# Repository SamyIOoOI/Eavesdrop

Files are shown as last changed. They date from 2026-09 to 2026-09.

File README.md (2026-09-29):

<h1 align="center">Eavesdrop</h1>

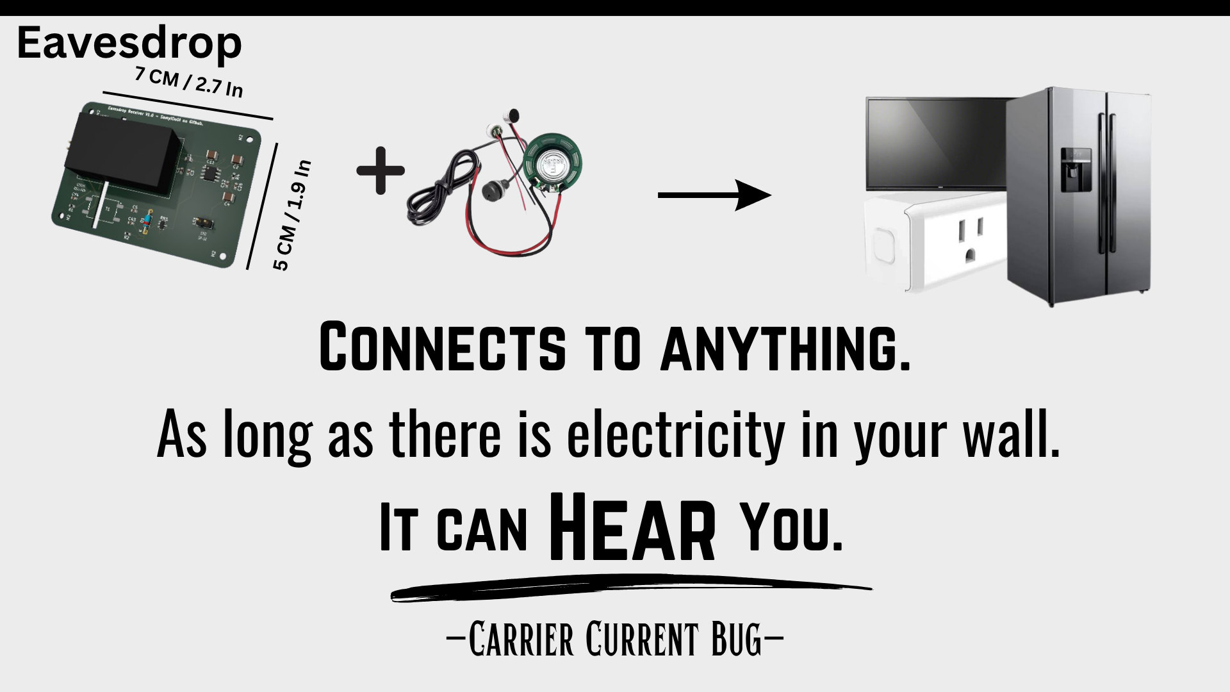
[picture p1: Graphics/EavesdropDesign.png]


### <p align="center">[Main Features](#main-features) **-** [Usage](#usage-of-eavesdrop) **-** [PCB & Schematic](#design) **-** [Gerber Files](/Eavesdrop/Gerber%20Files/) **-** [Kicad (Schematic & PCB)](/Eavesdrop/Kicad%20Source%20Files/)  **-** [BOM](#bom)  **-** [BOM (File)](/BOM/evasdrop.xlsx) **-** [Credits](#credits)</p>

## How would you feel if your own fridge was spying on you? Maybe even your tv, maybe the fryer, maybe the wall outlet you charge this device with. maybe even your charger. Well that could very well be a carrier bug. Just like Eavesdrop.

*A "current carrier bug" is a spy tool that records the sound inside the area its plugged in and sends it back through the AC power its connected to directly, evading most detection devices available in the market that rely on RF to detect these devices.*

----------------

**<p align="center">No matter where you are. The bug listens as long as there's electricity flowing in the bugged device.<p>**

---------------

## Main Features

- Undetectable (via RF Detectors that are commonly used)
- Secretive (but requires prior access to the room)

- **Can be planted into any device, your lamp, your tv, your pc, ANYTHING can become a bug with one plug.**

## Usage of Eavesdrop

1- Insert it into the outlet or any device that takes in power from the wall and make sure the microphone jack is connected to proper microphone element such as an electret mic.

2- Connect the passive & active AC wires to their respective locations via the male header on the pcb, each header reads if its N (neutral) or L (live). 
Reversal could cause irreversible damage. Use a test screw driver to make sure you're connecting the right ones.

3- connect the receiver , when required to listen to the broadcast, to an outlet that is in the same grid as the target room/building.

4- Make sure that both the receiver and the sender are at the same wavelength via calibration. Refer to the schemati for more details.

5- Use the volume control knob to increase/decrease th sound level.

<br>

<p align="center">Note that usage of Eavesdrop or any other spying device is illegal when taken out of personal hobby boundaries and used beyond one's own property. (If your device bleeds into the grid of neighbouring properties you may still be fined.) <br><br> I hold no responsiblity on the misuse of this project for illegal activities such as but not limited to: Unathorized Surveillance, Stalking, and damage to property.<br><br>My work is done for the sake of open-sourcing, eduction and self-learning. Not to inflict harm.<p>

## Design

Eavesdrop Sender Schematic

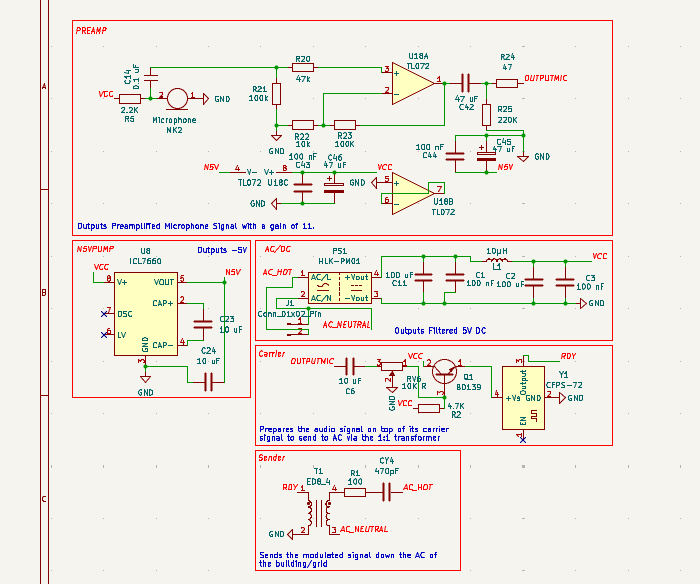
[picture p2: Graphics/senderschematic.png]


Eavesdrop Sender PCB

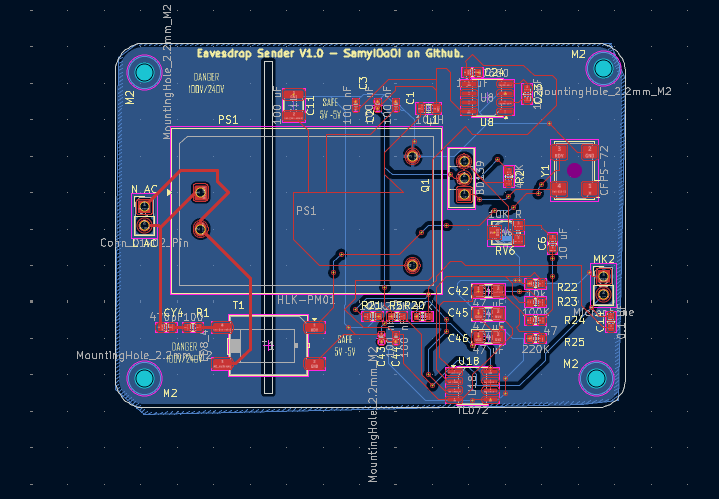
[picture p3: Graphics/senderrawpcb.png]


Eavesdrop Sender PCB (Model)

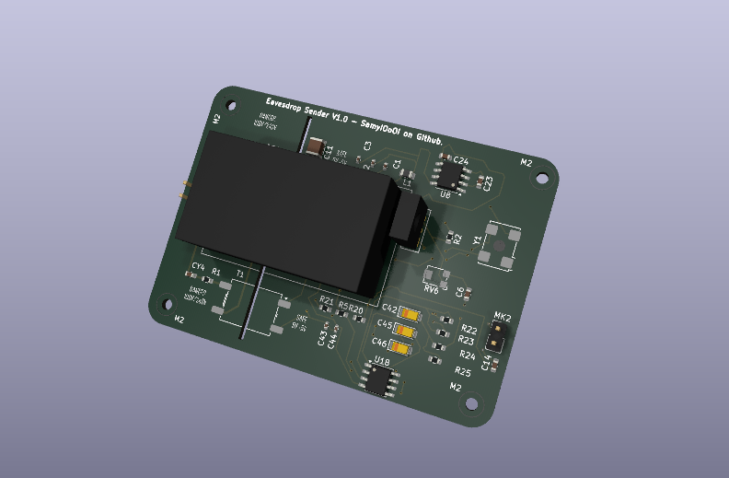
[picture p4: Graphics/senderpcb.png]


Eavesdrop Receiver Schematic

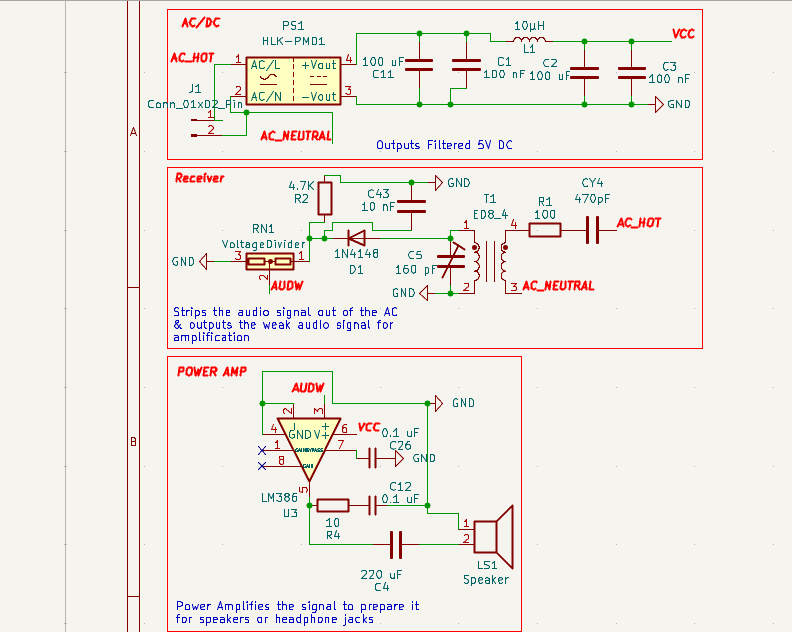
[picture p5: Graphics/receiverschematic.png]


Eavesdrop Receiver PCB

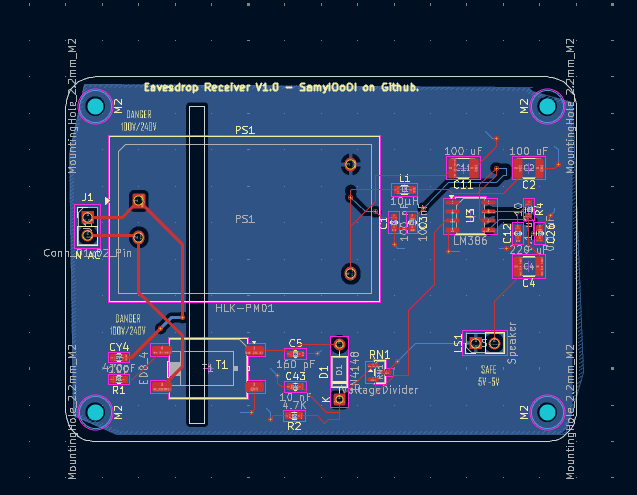
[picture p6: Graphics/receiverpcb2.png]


Eavesdrop Receiver PCB (Model)

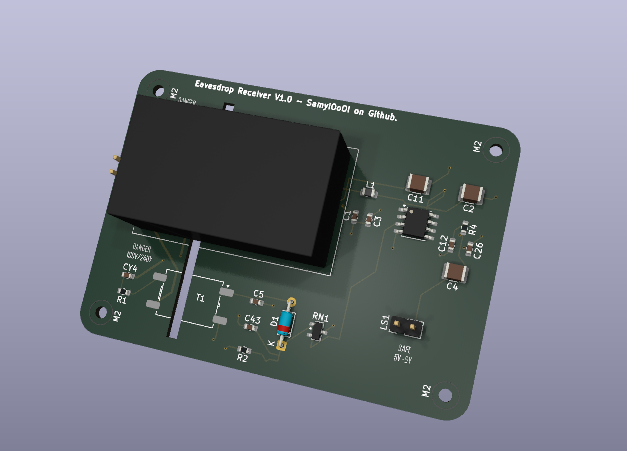
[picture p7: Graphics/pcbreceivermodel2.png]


## BOM

| **Part Name** | **Quantity** | **Price** | **Link** |
|---|---|---|---|
| **2.54mm 1x2 Pin Header** | 2 | 89.04 | https://www.digikey.com/en/products/detail/samtec-inc/TSW-102-26-S-S/1103922 |
| **Capacitor 0.1 uF** | 3 | 41.93 | https://www.digikey.com/en/products/detail/vishay-beyschlag-draloric-bc-components/K104K10X7RF5UH5/2356754 |
| **Capacitor 10 nF** | 1 | 5.18 | https://www.digikey.com/en/products/detail/samsung-electro-mechanics/CL21B103KBANNNC/3886673 |
| **Capacitor 10 uF** | 3 | 29.51 | https://www.digikey.com/en/products/detail/kemet/ESK106M050AC3DA/13176616 |
| **Capacitor 100 nF** | 6 | 83.87 | https://www.digikey.com/en/products/detail/vishay-beyschlag-draloric-bc-components/K104K10X7RF5UH5/2356754 |
| **Capacitor 100 uF** | 4 | 115.96 | https://www.digikey.com/en/products/detail/rubycon/35TZV100M6-3X8/3134900 |
| **Capacitor 160 pF** | 1 | 1.09 | https://www.digi-electronics.com/en/products/detail/murata-electronics/GCM1885C2A161JA16D/7169978.html |
| **Capacitor 220 uF** | 1 | 31.76 | https://www.lcsc.com/product-detail/C133440.html |
| **Capacitor 47 uF** | 3 | 65.23 | https://www.digikey.com/en/products/detail/rubycon/63ZLJ47M6-3X11/3134467 |
| **Capacitor 470pF** | 2 | 1.00 | https://uge-one.com/product/ceramic-capacitor-470pf/ |
| **Condenser Microphone** | 1 | 6.00 | https://makerselectronics.com/product/condenser-microphone-2-pins/ |
| **Crystal/Oscillator CFPS-72** | 1 | 168.77 | https://www.digikey.com/en/products/detail/ecs-inc/ECS-100AX-035/827253 |
| **Diode 1N4148** | 1 | 5.18 | https://www.digikey.com/en/products/detail/onsemi/1N4148/458603 |
| **IC ICL7660** | 1 | 51.30 | https://uge-one.com/product/icl7660/ |
| **IC LM386** | 1 | 55.91 | https://www.digikey.com/en/products/detail/texas-instruments/LM386N-1-NOPB/6284 |
| **IC TL072** | 1 | 24.48 | https://www.lcsc.com/product-detail/C7236.html |
| **Inductor 10µH** | 2 | 11.39 | https://www.digikey.com/en/products/detail/tdk/MLZ2012M100WTD25/4743190 |
| **Potentiometer 10K** | 1 | 96.29 | https://www.digikey.com/en/products/detail/tt-electronics-bi/P160KN-0QD15B10K/2408885 |
| **Power Supply HLK-PM01 (AC-DC 5V 3W)** | 2 | 320.00 | https://makerselectronics.com/product/hlk-pm01-ac-dc-power-module/ |
| **Resistor 10** | 1 | 0.15 | https://makerselectronics.com/product/carbon-resistor-10%cf%89-0-25w-through-hole/ |
| **Resistor 100** | 2 | 2.50 | https://uge-one.com/product/resistor-1w-carbon-film-5-tolerance-100r-ohm/ |
| **Resistor 100K** | 2 | 0.30 | https://makerselectronics.com/product/carbon-resistor-100k-0-25w/ |
| **Resistor 10K** | 1 | 0.10 | https://makerselectronics.com/product/carbon-resistor-10k%cf%89-0-125w-through/ |
| **Resistor 2.2K** | 1 | 0.10 | https://makerselectronics.com/product/carbon-resistor-2-2k%cf%89-0-125w-through-hole/ |
| **Resistor 220K** | 1 | 0.15 | https://makerselectronics.com/product/carbon-resistor-220k%cf%89-0-25w-through-hole/ |
| **Resistor 4.7K** | 2 | 0.50 | https://uge-one.com/product/carbon-resistor-0-25w-4-7k-ohm/ |
| **Resistor 47** | 1 | 1.00 | https://makerselectronics.com/product/carbon-resistor-47%cf%89-2w-through-hole/ |
| **Resistor 47K** | 1 | 0.15 | https://makerselectronics.com/product/carbon-resistor-47k%cf%89-0-25w/ |
| **Resistor VOLTAGEDIVIDER** | 1 | 0.15 | https://makerselectronics.com/product/carbon-resistor-100k-0-25w/ |
| **Speaker** | 1 | 60.00 | https://makerselectronics.com/product/speaker-8-ohm-10w-125x60mm/ |
| **Transformer ED8_4** | 2 | 755.84 | https://www.digikey.com/en/products/detail/pulse-electronics/HX0068ANL/3025742 |
| **Transistor BD139** | 1 | 4.50 | https://makerselectronics.com/product/bd139-1-5a-80v-npn-bipolar-power-transistor-to-126/ |
| **Total** | | 2029.33 EGP  | |

*Credits: BOM converted from XLSX to md on tableconvert.com*

## Credits

Made by SamyIOoOI on github under the GPL 3.0 Licence.



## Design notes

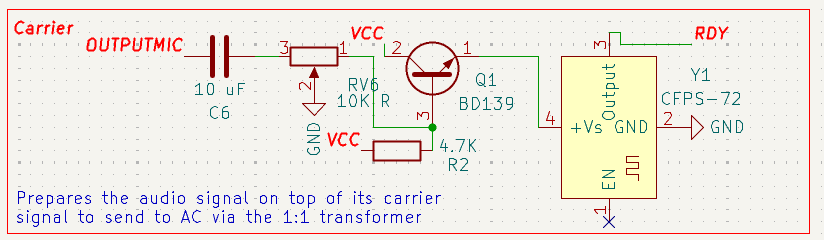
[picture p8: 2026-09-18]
Graphics/r.png

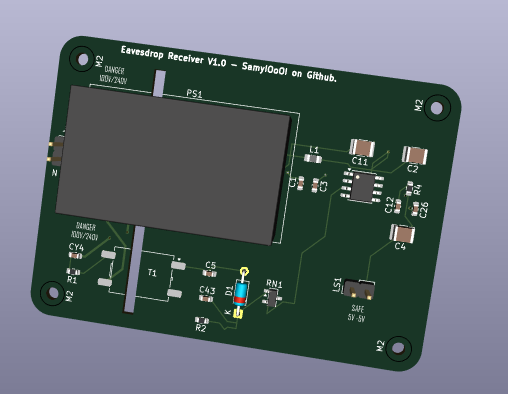
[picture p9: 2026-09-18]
Graphics/senderpcbpicture.png

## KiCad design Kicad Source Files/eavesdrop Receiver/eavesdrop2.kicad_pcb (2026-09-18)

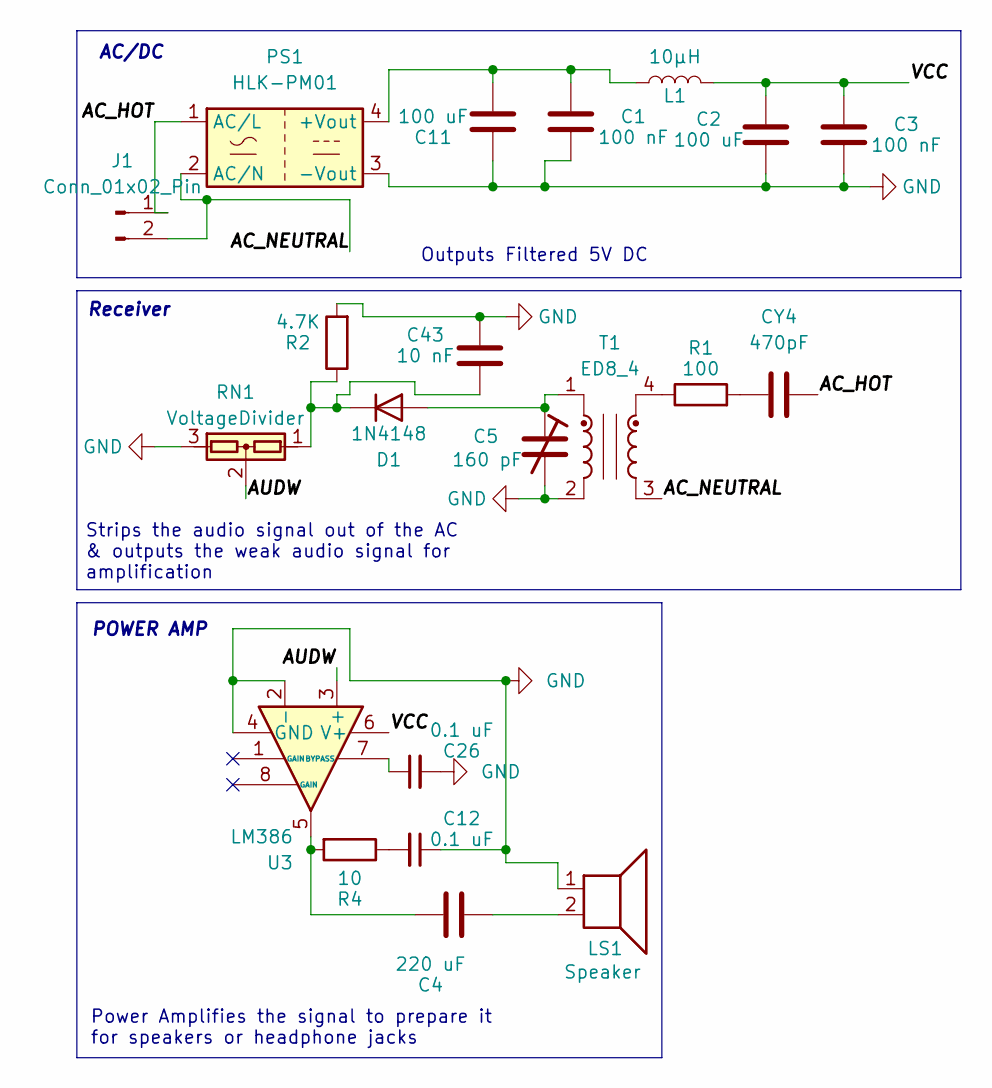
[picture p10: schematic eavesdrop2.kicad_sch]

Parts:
C1, C3: 100 nF; C_0603_1608Metric
C2, C11: 100 uF; C_1210_3225Metric
C4: 220 uF; C_1210_3225Metric
C5: 160 pF; C_0603_1608Metric
C12, C26: 0.1 uF; C_0603_1608Metric
C43: 10 nF; C_0603_1608Metric
CY4: 470pF; C_0603_1608Metric
D1: 1N4148; D_DO-35_SOD27_P7.62mm_Horizontal
J1: Conn_01x02_Pin; PinHeader_1x02_P2.54mm_Vertical
L1: 10µH; L_0805_2012Metric
LS1: Speaker; PinHeader_1x02_P2.54mm_Vertical
PS1: HLK-PM01; Converter_ACDC_Hi-Link_HLK-PMxx
R1: 100; R_0603_1608Metric
R2: 4.7K; R_0603_1608Metric
R4: 10; R_0603_1608Metric
RN1: VoltageDivider; SOT-23
T1: ED8_4; Transformer_ED8_4-Lead_10.5x8mm_P5mm
U3: LM386; SOIC-8_3.9x4.9mm_P1.27mm

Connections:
/AC_HOT: CY4.2, J1.1, PS1.1 (AC/L)
/AC_NEUTRAL: J1.2, PS1.2 (AC/N), T1.3
/AUDW: RN1.2, U3.3 (+)
/VCC: C2.2, C3.2, L1.2, U3.6 (V+)
GND: C1.1, C2.1, C3.1, C5.2, C11.1, C12.1, C26.2, C43.1, LS1.1, PS1.3 (-Vout), R2.2, RN1.3, T1.2, U3.2 (-), U3.4 (GND)
unnamed: C4.1, R4.2, U3.5
unnamed: C4.2, LS1.2
unnamed: C12.2, R4.1
unnamed: CY4.1, R1.2
unnamed: C5.1, D1.2 (A), T1.1
unnamed: C43.2, D1.1 (K), R2.1, RN1.1
unnamed: C1.2, C11.2, L1.1, PS1.4 (+Vout)
unnamed: R1.1, T1.4
unnamed: C26.1, U3.7 (BYPASS)

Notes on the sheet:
Strips the audio signal out of the AC & outputs the weak audio signal for amplification
Power Amplifies the signal to prepare it for speakers or headphone jacks
AC/DC
Receiver
POWER AMP
Outputs Filtered 5V DC

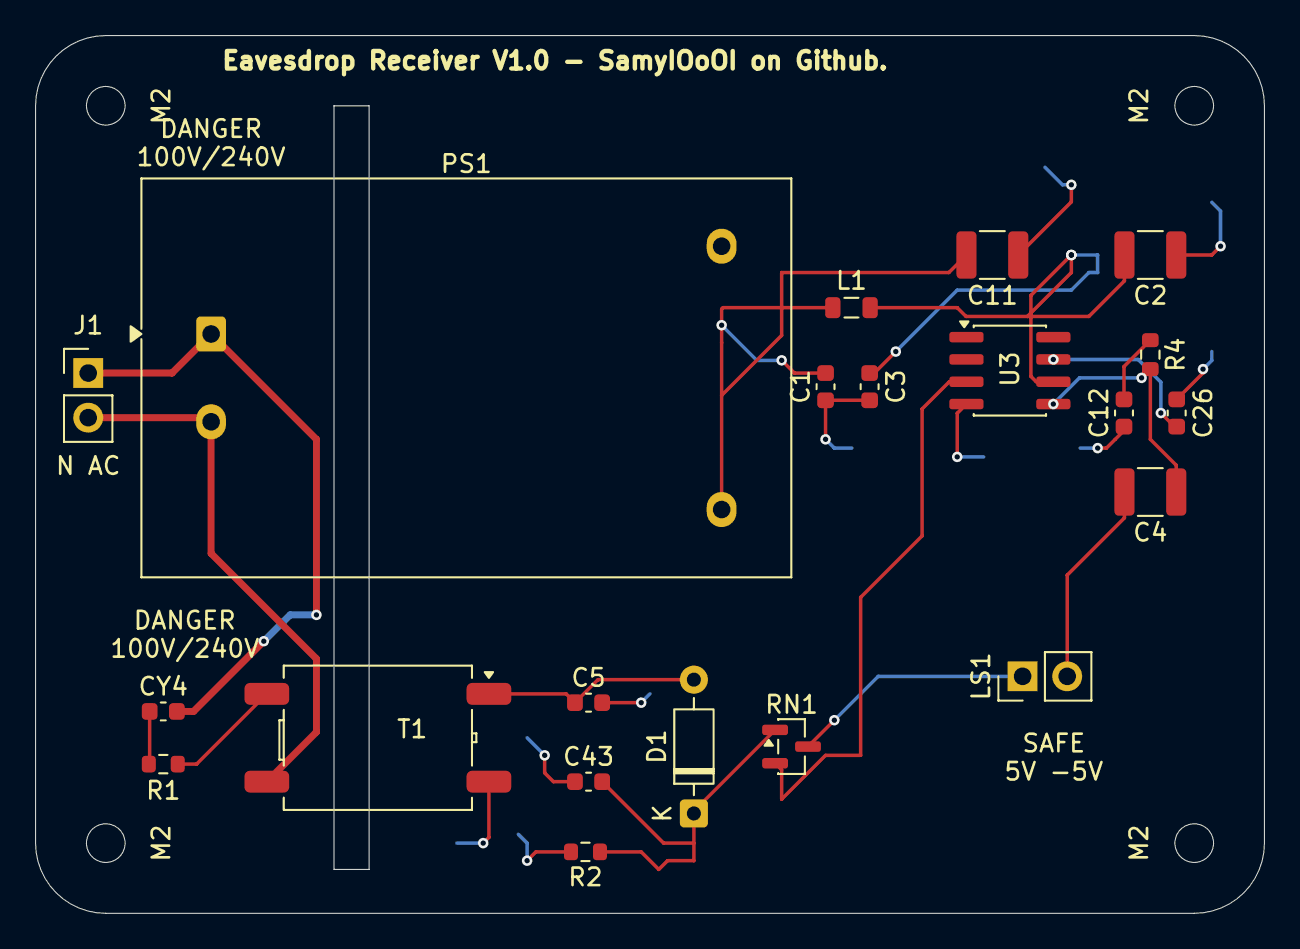
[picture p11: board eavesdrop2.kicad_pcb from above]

Board: 2 copper layers, 70.0 x 50.0 mm, 25 parts (0 on the bottom side), 14 nets.

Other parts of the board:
M2, M2#2, M2#3, M2#4: MountingHole_2.2mm_M2

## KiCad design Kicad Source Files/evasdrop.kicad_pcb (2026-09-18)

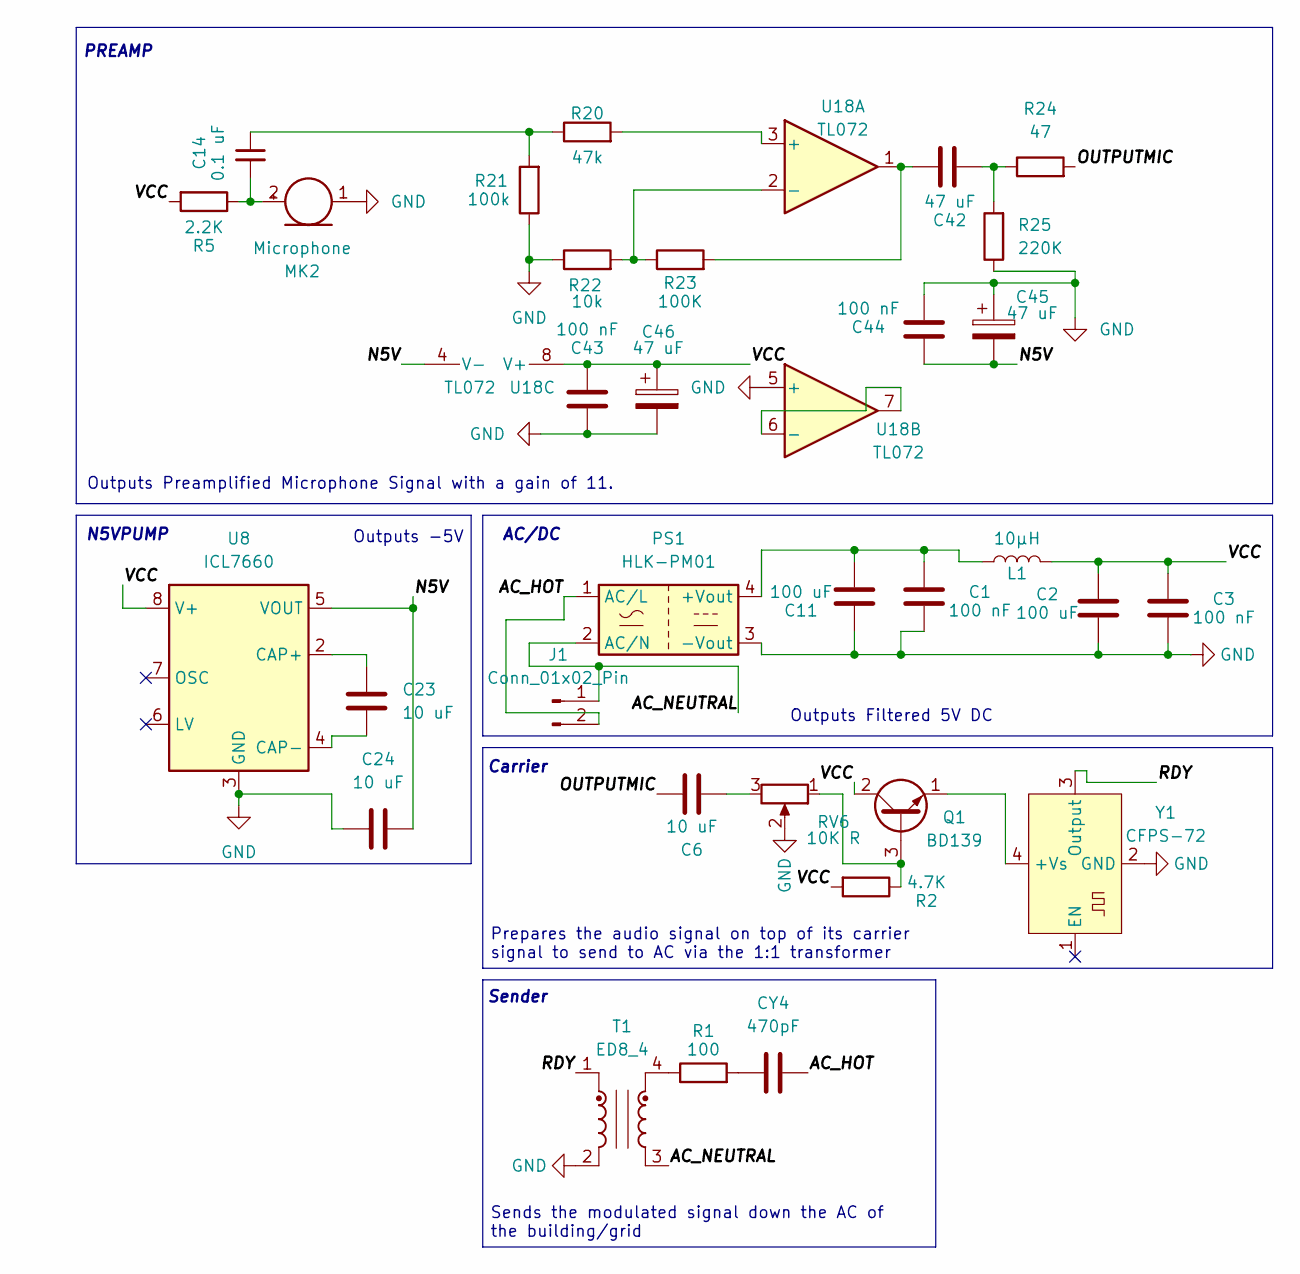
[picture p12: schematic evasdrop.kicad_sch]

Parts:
C1, C3, C43, C44: 100 nF; C_0402_1005Metric
C2: 100 uF; C_0402_1005Metric
C6, C23, C24: 10 uF; C_0603_1608Metric
C11: 100 uF; C_1210_3225Metric
C14: 0.1 uF; C_0603_1608Metric
C42, C45, C46: 47 uF; CP_EIA-3216-18_Kemet-A
CY4: 470pF; C_0603_1608Metric
J1: Conn_01x02_Pin; PinHeader_1x02_P2.54mm_Vertical
L1: 10µH; L_0805_2012Metric
MK2: Microphone; PinHeader_1x02_P2.54mm_Vertical
PS1: HLK-PM01; Converter_ACDC_Hi-Link_HLK-PMxx
Q1: BD139; TO-126-3_Vertical
R1: 100; R_0603_1608Metric
R2: 4.7K; R_0603_1608Metric
R5: 2.2K; R_0603_1608Metric
R20: 47k; R_0603_1608Metric
R21: 100k; R_0603_1608Metric
R22: 10k; R_0603_1608Metric
R23: 100K; R_0603_1608Metric
R24: 47; R_0603_1608Metric
R25: 220K; R_0603_1608Metric
RV6: 10K R; Potentiometer_Bourns_TC33X_Vertical
T1: ED8_4; Transformer_ED8_4-Lead_10.5x8mm_P5mm
U8: ICL7660; SOIC-8_3.9x4.9mm_P1.27mm
U18: TL072; SOIC-8_3.9x4.9mm_P1.27mm
Y1: CFPS-72; Oscillator_SMD_IQD_IQXO70-4Pin_7.5x5.0mm

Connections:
/AC_HOT: CY4.2, J1.2, PS1.1 (AC/L); also elsewhere on the board
/AC_NEUTRAL: J1.1, PS1.2 (AC/N), T1.3; also elsewhere on the board
/N5V: C24.1, C44.2, C45.2, U8.5 (VOUT), U18.4 (V-)
/OUTPUTMIC: C6.1, R24.2
/RDY: T1.1, Y1.3 (Output)
/VCC: C2.2, C3.2, C43.1, C46.1, L1.2, Q1.2 (C), R2.2, R5.2, U8.8 (V+), U18.8 (V+)
GND: C1.1, C2.1, C3.1, C11.1, C24.2, C43.2, C44.1, C45.1, C46.2, MK2.1 (-), PS1.3 (-Vout), R21.1, R22.1, R25.1, RV6.2, T1.2, U8.3 (GND), U18.5 (+), Y1.2 (GND)
unnamed: C6.2, RV6.3
unnamed: C14.1, R20.1, R21.2
unnamed: C42.1, R23.2, U18.1
unnamed: C42.2, R24.1, R25.2
unnamed: CY4.1, R1.2
unnamed: C14.2, MK2.2 (+), R5.1
unnamed: C1.2, C11.2, L1.1, PS1.4 (+Vout)
unnamed: Q1.3 (B), R2.1, RV6.1
unnamed: Q1.1 (E), Y1.4 (+Vs)
unnamed: R1.1, T1.4
unnamed: C23.1, U8.2 (CAP+)
unnamed: C23.2, U8.4 (CAP-)
unnamed: R20.2, U18.3 (+)
unnamed: R22.2, R23.1, U18.2 (-)
unnamed: U18.6 (-), U18.7

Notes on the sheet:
Sender
Outputs Preamplified Microphone Signal with a gain of 11.
PREAMP
Carrier
AC/DC
Prepares the audio signal on top of its carrier signal to send to AC via the 1:1 transformer
N5VPUMP
Sends the modulated signal down the AC of the building/grid
Outputs -5V
Outputs Filtered 5V DC

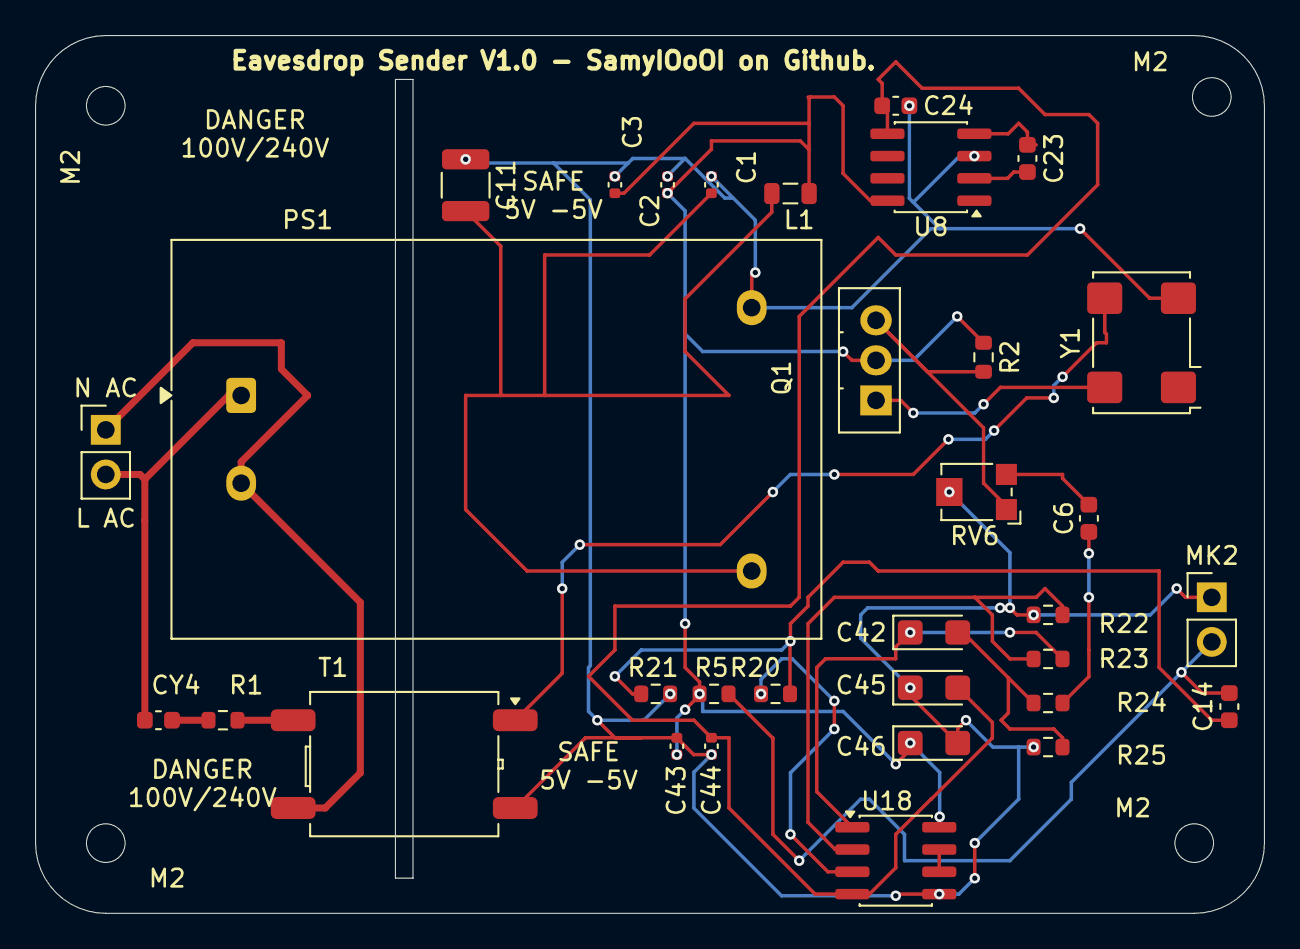
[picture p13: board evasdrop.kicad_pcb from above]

Board: 2 copper layers, 70.0 x 50.0 mm, 37 parts (0 on the bottom side), 22 nets.

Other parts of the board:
M2, M2#2, M2#3, M2#4: MountingHole_2.2mm_M2
N AC: Conn_01x02_Pin; PinHeader_1x02_P2.54mm_Vertical

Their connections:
/AC_HOT: N AC.2; also elsewhere on the board
/AC_NEUTRAL: N AC.1; also elsewhere on the board

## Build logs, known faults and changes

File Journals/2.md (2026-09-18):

# Drawing the schematics | Journal Time: None (LAPSED)

`I like to admire a schematic after its finished; the diagram just seems watch-worthy...`

--------------

### The first thing that was needed to, you know, record and spy on someone's via a microphone, was guess what? A microphone and a micromp circuit. Luckily for this part I already had made it before on my project RetroCom. So I copied that and tweaked it and changed the gain to 11 to fit the new role (of literally being dumbed into the electricity of a building).

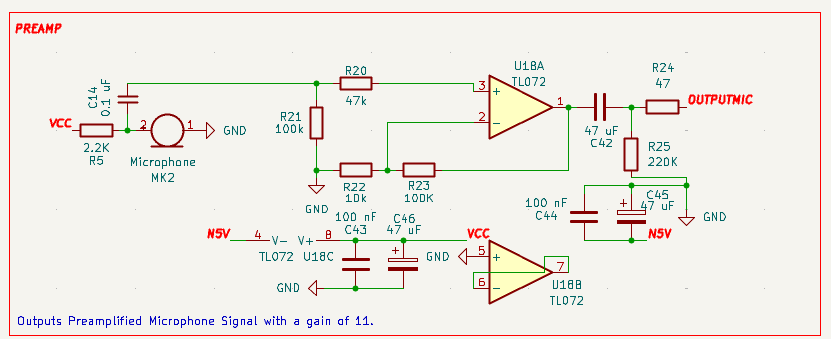
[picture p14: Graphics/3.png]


A picture of the PreAmp Circuit I'm talking about. 
Present in the sender circuit of Evasdrop.

### After that was sorted, I quickly tackled power by using an AC/DC Converter module. I knew I couldn't use a transormer and a regulator because that would be too heavy for this kind of "device" ofc. The module has a filter attached to deal with the bad signal noise.
 
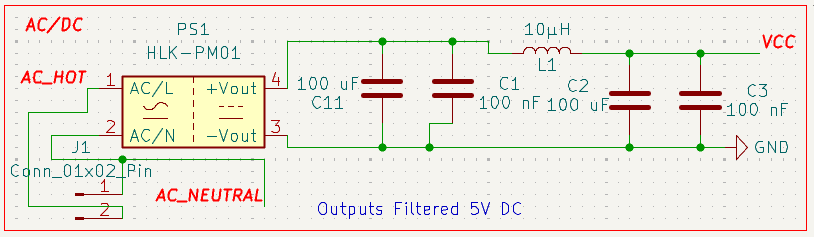
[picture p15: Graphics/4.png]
 

### Additionally, the project uses another borrowed aspect from my project retrocom, the icl7660 pump to output -5V to be used in the preamp phase. Although I wouldn't really call it an "aspect" since its so simple.

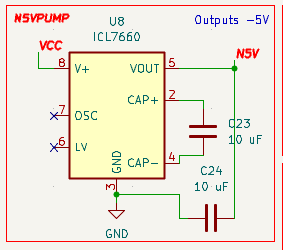
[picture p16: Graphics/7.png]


## The most important part

### Now the question arises.. where are the new stuff? how does the system work? how did you apply it? 

### A really really simple, yet super effective (maybe not so simple) process is used. 

### First the voice is recorded and preamplified and the whole device is supplied from the outlet or whatever way its getting access to its ac source from. Afterwards that voice/sound is put through an oscillator so as to put it on a carrier wave. Afterwards that carrier wave is sent on the local AC with a 1:1 transformer. 

### Oscillation is done via a diode/transistor/crystal system as shown below

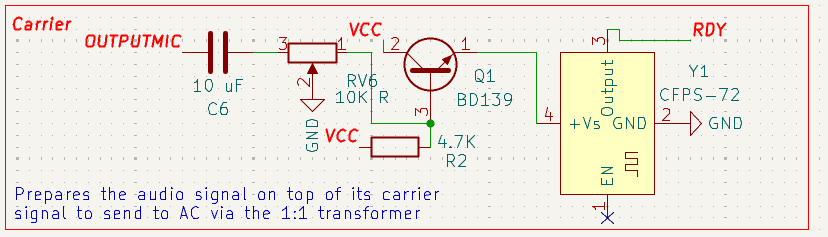
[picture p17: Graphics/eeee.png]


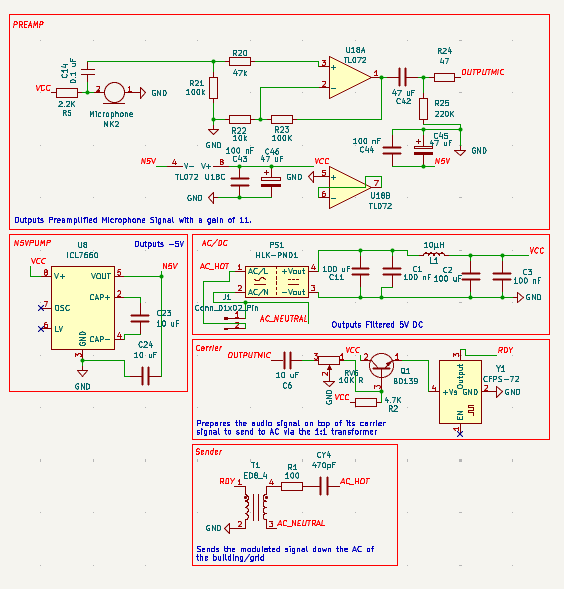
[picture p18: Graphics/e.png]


### After working on the schematic and debugging till i came to the final result shown above I started to think about the pcb. Which I ended up making two differnet pcbs, one for the transmission bug and another for the receive bug. remember bug just means espionage device in this context! 

### The sizes were 7*5 cm for each board. Which means these things can fit and bug practically any device that conencts to the wall.

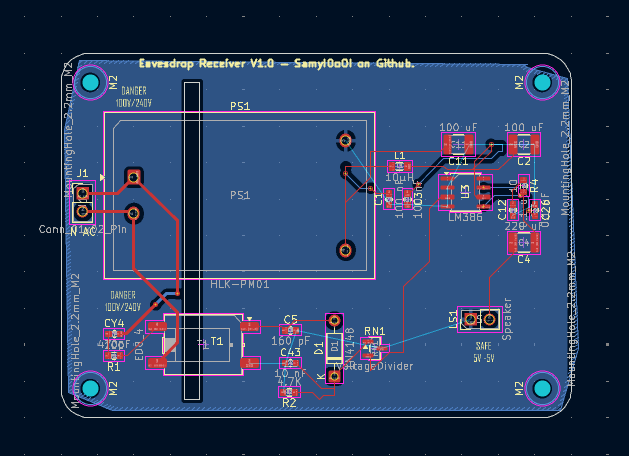
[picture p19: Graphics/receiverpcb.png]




### As for the receiver bug, it was straight forward. All I had to do was swap the TLO72 PREAMP with a POWER AMP LM386 to power up speakers/headphones. I also had to get rid of no longer useful components such as the ICL7660 that outputted the -5V Rail as that rail was no longer needed with the removal of the TL072. As for the RF modulation circuit I just needed to reverse the logic. Note that both the Receiver and Sender must be set to equal frequencies to work.


Receiver Circuit Schematic

### I expected the biggest in size to be the transformer but it actually turned out to be the AC/DC module by a massive margin.

## In the end I'd like to say that this project def opened my eyes on a whole new genre of things that I hope I will be able to develop later

 also time to write the readme and go to sleep... I'm barely awake its 6:07 AM. Have fun reviewer!

https://lapse.hackclub.com/timelapse/ORzzZJmxVIvP

https://lapse.hackclub.com/timelapse/vQRUEF0Iv1QD

https://lapse.hackclub.com/timelapse/8wdrSyqmCmyq

https://lapse.hackclub.com/timelapse/1Zpe0rNPwKQ_

https://lapse.hackclub.com/timelapse/MasJyytMrEYQ

# Made for Hack Club Live YSWS with love <3 (& a lack of sleep.)

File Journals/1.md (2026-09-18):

# Getting the Idea | Time: Not tracked

*`pssst I'm writing this while I'm barely even awake, please turn a blind eye to misspellings or sentences that are half missing`*

## When seb announced the competition I decided that, after thinking about it to make something **cool**; it is a once in idk how much time fun event afterall .

### At first I thought about the typical projects, jammer maybe drone etc. But it came with two problems. 1- There isn't enough time, for reference I am currently writing this as 5:26 AM to finish in time. 2- A lot of them I considered to be boring. Countless of drones and usb hubs out there am     I right?

### As a result I went another route. I wanted something cool & creative. Spy tools! this topic in particular gathered my attention as I'm personally interested in these type of things.

### Out of of other equally cool things such as a laser sound evasdropping device that could listen to a room with a laser pointed at its windows I selected this, the current carrier bug instead. Why? 1- It does not require firmware 2- The thought that you can spy on someone with merely their electricity was super cool 3- moving SOUND in WALL OUTLETS. ^,^

### And so I continued reading about it and the other topics. At one point I had the idea of summing together laser spying, RF bugs, and the current carrier bug together into a multi module project but I scrapped that issue because all but the latter require firmware, which would be impractical imo during this timewindow + they are not as certain.

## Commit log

2026-09-18 source files and empty journal.md
    [eavesdrop2.kicad_pcb, eavesdrop2.kicad_sch, evasdrop.kicad_pcb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]
2026-09-18 uploading gerber files and graphics to use in read
    [eavesdrop2-B_Cu.gbr, eavesdrop2-B_Mask.gbr, eavesdrop2-B_Paste.gbr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]
2026-09-18 fixed an issue with GND of the receiver circuit
    [eavesdrop2.kicad_pcb]
2026-09-29 added BOM
    [evasdrop.xlsx]
2026-09-29 now clicking on bom file acc takes u to the file
